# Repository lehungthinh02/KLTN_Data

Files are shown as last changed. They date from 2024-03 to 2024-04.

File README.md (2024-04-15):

# Bảng dữ liệu thiết kế

Thông tin chi tiết về các module được sử dụng trong thiết kế:

## Module (NB-IOT ME310G1)

| Thuộc tính | Giá trị |
|---|---|
| Điện áp nguồn | 3.8V |
| Dòng điện | 700 mA |
| Giao tiếp | UART, SPI, LTE  |

## MCU (PIC32MM0256GPM064)

| Thuộc tính | Giá trị |
|---|---|
| Điện áp nguồn | 2.0V đến 3.6V |
| Dòng điện | 0.65 μA đến 5 μA |
| Giao tiếp | SPI, I2C, UART, USB-OTG|

# Nguồn tài liệu

- [File 3D và danh sách bom](https://www.thingiverse.com/thing:6439737)

# Sơ đồ thiết kế

Mô tả quy trình hoạt động:

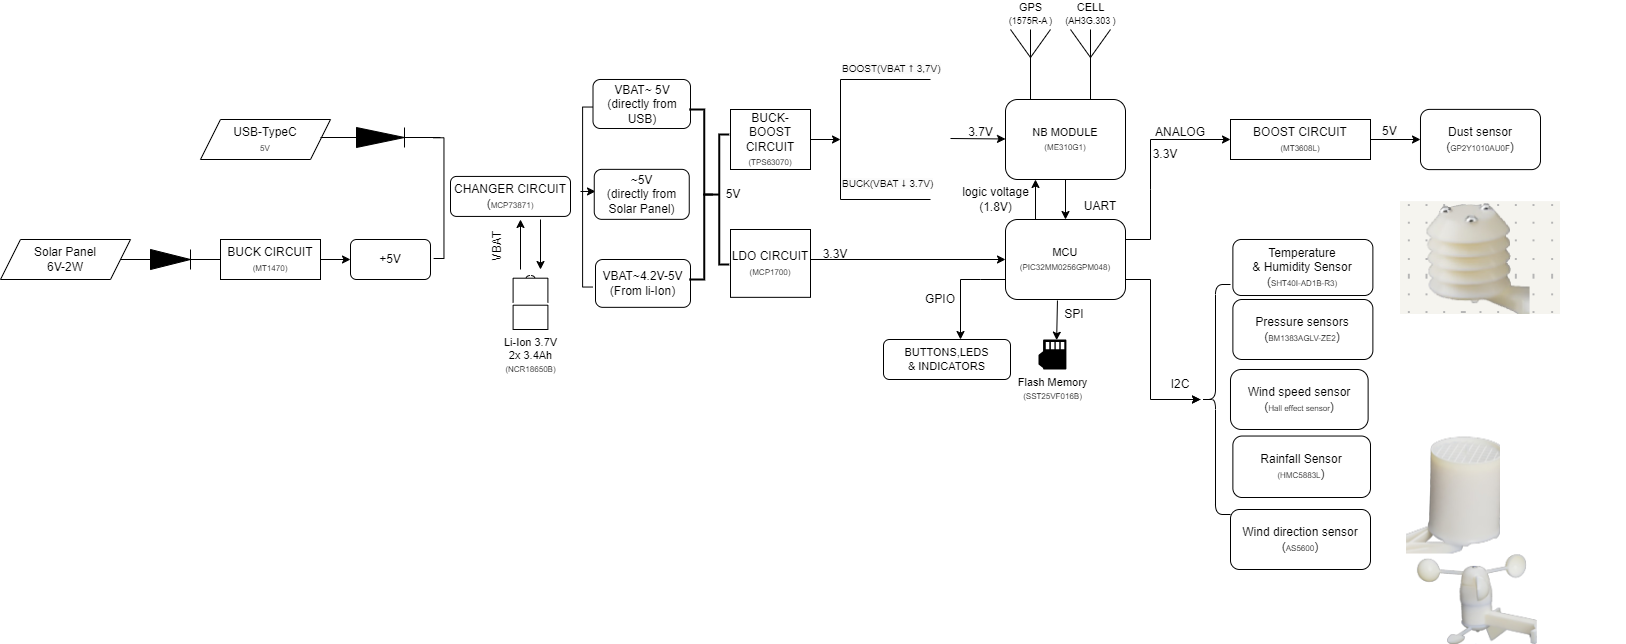
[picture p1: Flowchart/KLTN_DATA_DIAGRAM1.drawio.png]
flowchart


# Case of Board

Mô tả về case bảo vệ board:

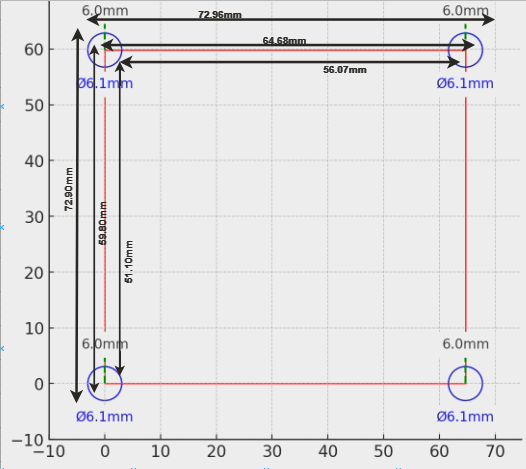
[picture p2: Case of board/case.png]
Case of Board


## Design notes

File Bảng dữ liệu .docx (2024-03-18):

Cảm biến | Điện áp nguồn | Dòng điện | Giao tiếp
Nhiệt độ-độ ẩm (HPP845E034R5) | 3.8v | 0,65 mA | I2C
Áp suất (BM1383AGLV) | 3.3v | - | I2C
Cảm biến bụi (GP2Y1010AU0F) | 5v | 11 mA | Analog
Cảm biến hướng gió (AS5600) | 3.3v | 1,5 mA | I2C
Cảm biến tốc độ gió (Hall A3144) | 4.5v-24v | - | Analog
Cảm biến từ trường đo lượng mưa(HMC5883L) | 2.16v -3.6v | 100μA | I2C

NB-IOT(ME310G1)
Điện áp nguồn | 3.8v
Dòng điện | 700 mA
Giao tiếp | UART,SPI, LTE Cat-M1/Cat-NB1,DCS/PCS, GSM

MCU(PIC32MM0256GPM064)
Điện áp nguồn | 2.0v đến 3.6v
Dòng điện | 0.65 μA đến 5 μA
Giao tiếp | SPI,I2C,UART,USB-OTG,CAN,LIN.

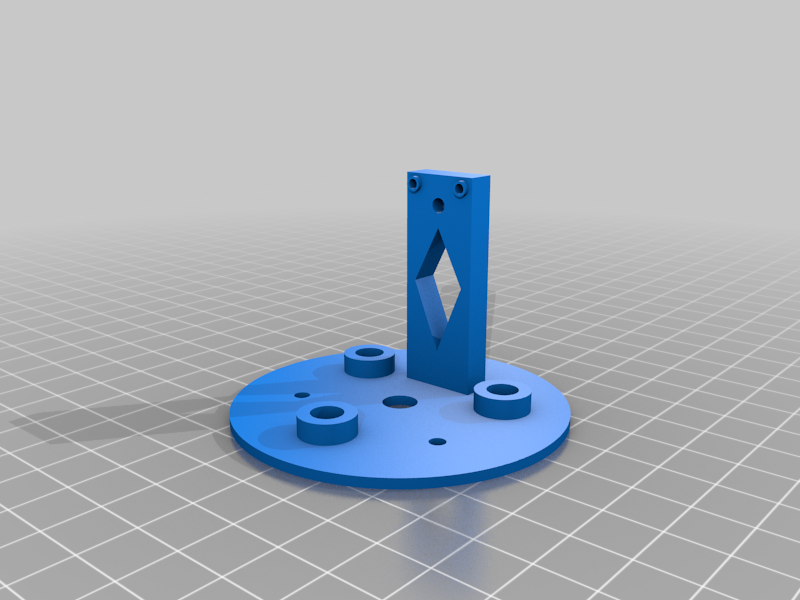
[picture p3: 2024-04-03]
Hardware/Enclosure/images/645dd349-c03a-4ee8-80c0-8387001d7b49.png

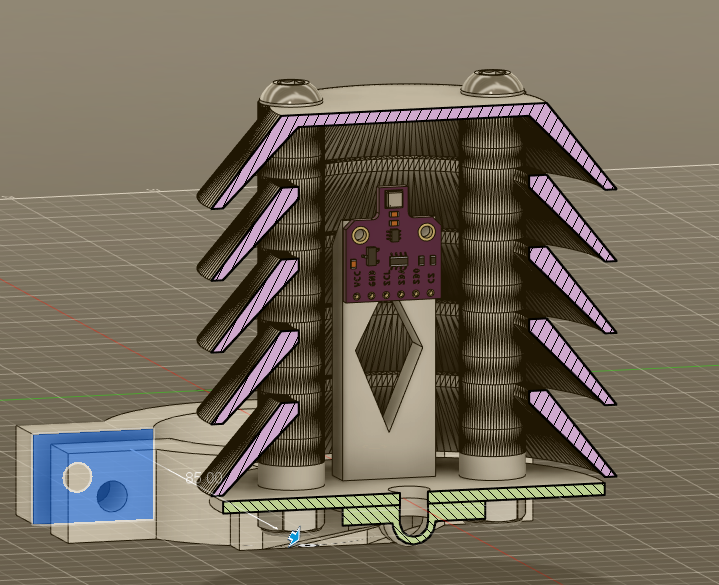
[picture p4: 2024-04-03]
Hardware/Enclosure/images/4b5391d4-0b75-4b54-ad87-2e042f95fe6b.png

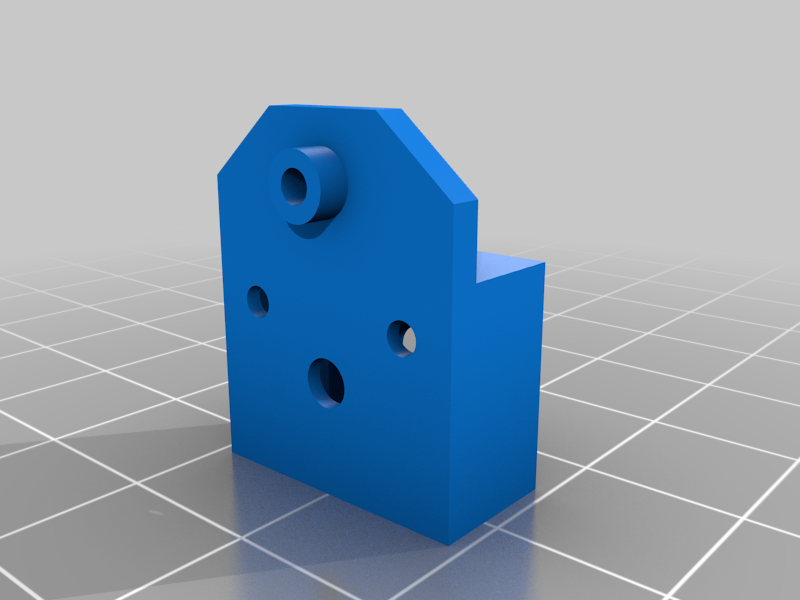
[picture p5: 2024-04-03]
Hardware/Enclosure/images/2f302a85-7f2c-48bd-ab72-bc9634dedcbf.png

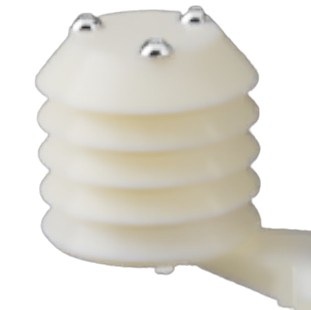
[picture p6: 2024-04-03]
Hardware/Enclosure/images/HumiditySensor.png

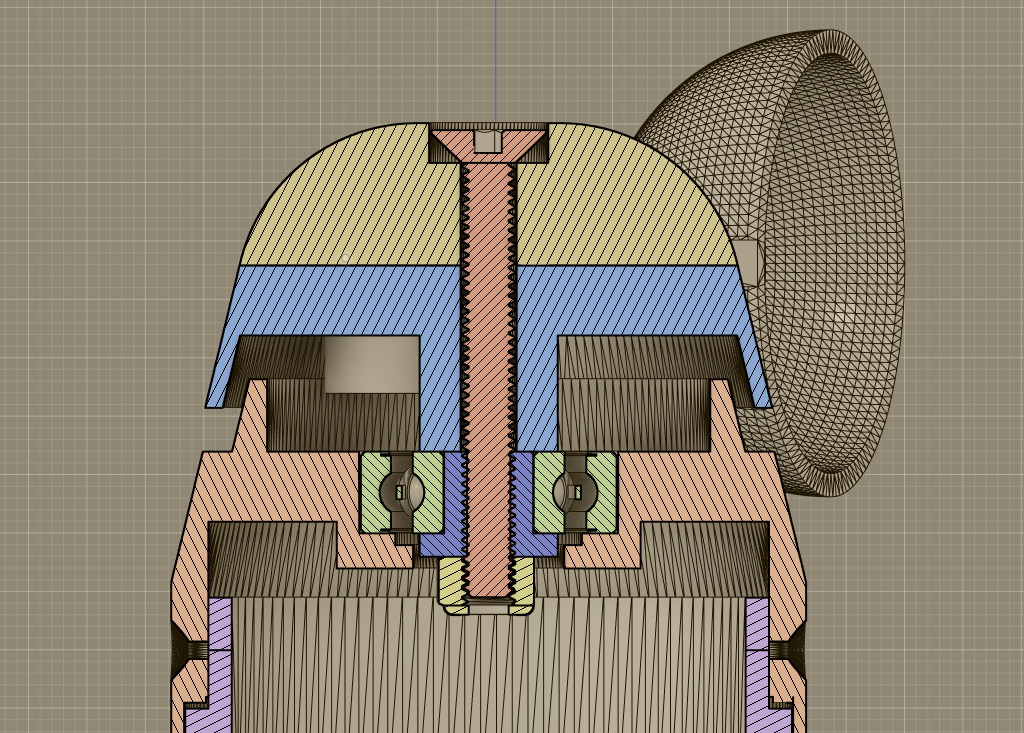
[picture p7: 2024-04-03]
Hardware/Enclosure/images/2bd4bd71-de33-4c61-b7e4-2078deda2e9a.png

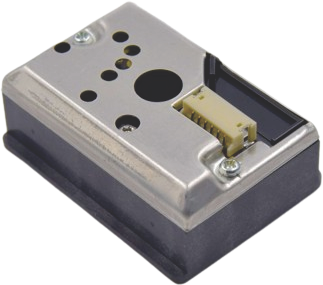
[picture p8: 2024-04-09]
Hardware/Enclosure/images/Untitled-1_Images/Untitled-1_ImgID1.png

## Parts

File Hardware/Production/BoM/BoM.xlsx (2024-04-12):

# | MNP | MFT | Description | Reference | Qty | Price | Sub-Price | Stock Link
1 | ZH1.5-10CM | OEM | ZH1.5 Bus Wire Female-Female Connector 6 Way, Pitch 1.5mm, Length 10cm | CB1 | 1 | $0.15400 | $0.15400 | https://www.thegioiic.com/day-bus-zh1-5-cai-cai-6-tiep-diem-1-5mm-dai-10cm
2 | IDC8x2-30CM | OEM | IDC Cable Female-Female Same Direction 8-Way Connector, Pitch 2.0mm, Length 30cm | CB2 | 1 | $1.00900 | $1.00900 | https://www.thegioiic.com/day-cap-idc-cai-cai-cung-huong-8-tiep-diem-2-0mm-dai-30cm
3 | IDC8x2-50CM | OEM | IDC Cable Female-Female Same Direction 8-Way Connector, Pitch 2.0mm, Length 50cm | CB3 | 1 | $1.22800 | $1.22800 | https://www.thegioiic.com/day-cap-idc-cai-cai-cung-huong-8-tiep-diem-2-0mm-dai-50cm
4 | GP2Y1014AU | SHARP | DUST SENSOR UNIT | MD3 | 1 | $4.07900 | $4.07900 | https://www.thegioiic.com/gp2y1014au-cam-bien-bui-pm2-5
~~5~~ | ~~SOLAR9V-2W-115x115x3~~ | ~~OEM~~ | ~~SOLAR CELL 2W 9V 220MA 115x115x3MM~~ | ~~J2~~ | ~~1~~ | ~~$2.85100~~ | ~~$2.85100~~ | ~~https://www.thegioiic.com/tam-nang-luong-mat-troi-2w-9v~~
6 | 1575R-A | AntennaHome | GPS ACTIVE ANT 19X19 IPEX CONNECTOR RF CABLE 10CM | MD2 | 1 | $1.05300 | $1.05300 | https://www.thegioiic.com/1575r-a-ang-ten-active-gps-19x19-dau-ipex-cap-rf-10cm
~~7~~ | ~~AH3G.303~~ | ~~AntennaHome~~ | ~~ANTENNA SMD 2G/3G/4G 690~2700MHz~~ | ~~ANT1~~ | ~~1~~ | ~~$1.09600~~ | ~~$1.09600~~ | ~~https://www.thegioiic.com/ah3g-303-ang-ten-smd-2g-3g-4g-690-2700mhz~~
8 | PRT-12895 | SparkFun | BATT LITH-ION 3.7V 2.6AH 18650 | BAT1,BAT2 | 2 | $1.40400 | $2.80800 | https://www.thegioiic.com/pin-sac-18650-1800mah-3-6v-4-2v
9 | CL10B104KA8NNNC | Samsung | CAP CER 0.1UF 25V X7R 0603 | C1,C6,C12,C16,C17,C25,C27,C34,C41,C42,C46,C47,C51,C61,C66,C70,C74 | 17 | $0.00830 | $0.14110 | https://www.thegioiic.com/tu-gom-0603-100nf-0-1uf-25v
10 | CL10C101JB8NNNC | Samsung | CAP CER 100PF 50V C0G/NP0 0603 | C4,C9,C10,C11,C13,C15,C23,C68,C69 | 9 | $0.00830 | $0.07470 | https://www.thegioiic.com/tu-gom-0603-100pf-50v
11 | CL10B225KP8NNNC | Samsung | CAP CER 2.2UF 10V X7R 0603 | C8,C31,C36,C44,C50,C55,C60 | 7 | $0.01800 | $0.12600 | https://www.thegioiic.com/tu-gom-0603-2-2uf-10v
12 | CL10C8R2DB8NNNC | Samsung | CAP CER 8.2PF 50V C0G/NP0 0603 | C28,C29 | 2 | $0.00830 | $0.01660 | https://www.thegioiic.com/tu-gom-0603-8-2pf-50v
13 | CL10C220JB8NFNC | Samsung | CAP CER 22PF 50V C0G/NP0 0603 | C32,C33,C35,C37,C38,C39,C40,C43,C45,C48,C52,C53,C54,C56,C59,C71,C73 | 17 | $0.00830 | $0.14110 | https://www.thegioiic.com/tu-gom-0603-22pf-50v
14 | CL21A106KOQNNNE | Samsung | CAP CER 10UF 16V X5R 0805 | C2,C3,C7,C14,C18,C21,C22,C24,C30,C62,C63,C64,C67,C75 | 14 | $0.01700 | $0.23800 | https://www.thegioiic.com/tu-gom-0805-10uf-16v
15 | TAJC227K006RNJ | AVX | CAP ALUM 220UF 20% 6.3V SMD 2312 | C19,C20,C26,C49,C65,C72 | 6 | $0.24100 | $1.44600 | https://www.thegioiic.com/tu-tantalum-220uf-6-3v-2312-tajc227k006rnj
16 | UUD1E471MNL1GS | Nichicon | CAP ALUM 470UF 20% 25V SMD | C5 | 1 | $0.08800 | $0.08800 | https://www.thegioiic.com/tu-nhom-smd-470uf-25v-10x10-5mm
17 | PH2RA-04-UA | Adam Tech | CONN HEADER R/A 2x2POS 2.54MM | J3 | 1 | $0.11000 | $0.11000 | https://www.thegioiic.com/hang-rao-duc-doi-2-54mm-80-chan-cong-2-hang-xuyen-lo
18 | PR20B05VBDN | METZ | PIN HEADER, THR, DUAL ROW, 1.27 | J4 | 1 | $0.19700 | $0.19700 | https://www.thegioiic.com/hang-rao-duc-doi-1-27mm-80-chan-2-hang-cao-7-2mm-xuyen-lo
19 | SS26 | MDD | DIODE SCHOTTKY 60V 2A SMA | D1,D2,D8 | 3 | $0.01800 | $0.05400 | https://www.thegioiic.com/ss26-sma-diode-schottky-2a
20 | DPS368XTSA1 | Infineon | SENSOR 17.4PSIG 24BIT 8VLGA | U14 | 1 | $3.18000 | $3.18000 | https://www.digikey.com/en/products/detail/infineon-technologies/DPS368XTSA1/10244079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
21 | MF-MSMF075/24-2 | Bourns | PTC RESET FUSE 24V 750MA 1812 | F1 | 1 | $0.15400 | $0.15400 | https://www.thegioiic.com/mf-msmf075-24-2-cau-chi-tu-phuc-hoi-1812-24v-0-75a
22 | XH2.54-4P-R | OEM | PIN HEADER R/A 1x4POS 2.54MM | J1 | 1 | $0.01300 | $0.01300 | https://www.thegioiic.com/dau-xh-2-54mm-4-chan-cong-xuyen-lo
23 | DF11-8DP-2DSA(08) | Hirose | CONN HEADER VERT 8POS 2MM | J6,J7,J8 | 3 | $0.07900 | $0.23700 | https://www.thegioiic.com/cong-dc3-8-chan-2-hang-2-0mm-chan-thang
24 | S6B-ZR-SM4A-TF | JST | CONN HEADER SMD R/A 6POS 1.5MM | U11 | 1 | $0.03500 | $0.03500 | https://www.thegioiic.com/dau-zh-1-5mm-6-chan-dan-smd-nam-ngang
25 | HBLS1608-47NJ | HYHONGYEX | FIXED IND 47NH 380MA 700MOHM SMD 0603 | L3 | 1 | $0.01800 | $0.01800 | https://www.thegioiic.com/hbls1608-47nj-cuon-cam-47nh-0603-380ma
26 | BK2125HS101-T | Taiyo Yuden | FERRITE BEAD 100 OHM 0805 1LN | FT1 | 1 | $0.01800 | $0.01800 | https://www.thegioiic.com/bk2125hs101-t-ferrite-beads-100-ohm-0805
27 | SDE0604A-2R2M | Bourns | FIXED IND 2.2UH 4.35A 31MOHM SMD 5852 | L1 | 1 | $0.04400 | $0.04400 | https://www.thegioiic.com/cuon-cam-dan-smd-cd53-5852-2r2-2-2uh-3-5a
28 | SDE0805A-100M | Bourns | FIXED IND 10UH 3.2A 70 MOHM SMD | L2,L4 | 2 | $0.04400 | $0.08800 | https://www.thegioiic.com/cuon-cam-dan-smd-cd75-7855-100-10uh-2-3a
29 | B1931USD-20D000814U1930 | Harvatek | LED RED DIFFUSED 0603 SMD | D3 | 1 | $0.01500 | $0.01500 | https://www.thegioiic.com/led-do-0603-dan-smd-trong-suot-harvatek
30 | B1931NG--20D001114U1930 | Harvatek | LED GREEN DIFFUSED 0603 SMD | D4 | 1 | $0.01500 | $0.01500 | https://www.thegioiic.com/led-xanh-la-0603-dan-smd-trong-suot-harvatek
31 | B1911UD--20D001014U1930 | Harvatek | LED ORANGE DIFFUSED 0603 SMD | D5 | 1 | $0.01500 | $0.01500 | https://www.thegioiic.com/led-cam-0603-dan-smd-trong-suot-harvatek
32 | E1221NB--05D000814U1930 | Harvatek | LED BLUE DIFFUSED 0603 SMD | D7 | 1 | $0.01500 | $0.01500 | https://www.thegioiic.com/led-xanh-duong-0603-dan-smd-trong-suot-harvatek
33 | TPS630701RNMR | TI | IC REG BCK BST 5V 2A 15VQFN | U2 | 1 | $1.89000 | $1.89000 | https://www.digikey.com/en/products/detail/texas-instruments/TPS630701RNMR/6175215
34 | AC0603JR-071KL | YAGEO | RES SMD 1K OHM 5% 1/10W 0603 | R1,R6,R10,R13,R14,R15,R26,R28,R31,R32,R36 | 11 | $0.00140 | $0.01540 | https://www.thegioiic.com/dien-tro-1-kohm-0603-5-
35 | RC0603FR-075K1L | YAGEO | RES SMD 5.1K OHM 1% 1/10W 0603 | R2,R5,R23,R24 | 4 | $0.00200 | $0.00800 | https://www.digikey.com/en/products/detail/yageo/RC0603FR-075K1L/727268
36 | RC0603FR-0710KL | YAGEO | RES SMD 10K OHM 1% 1/10W 0603 | R3,R4,R9,R12,R16,R18,R20,R22,R25,R30,R35 | 11 | $0.00200 | $0.02200 | https://www.thegioiic.com/dien-tro-10-kohm-0603-1-
37 | AC0603FR-0775KL | YAGEO | RES SMD 75K OHM 1% 1/10W 0603 | R7,R34 | 2 | $0.00200 | $0.00400 | https://www.thegioiic.com/dien-tro-75-kohm-0603-1-
38 | RT0603FRE0736KL | YAGEO | RES SMD 36K OHM 1% 1/10W 0603 | R8 | 1 | $0.00200 | $0.00200 | https://www.digikey.com/en/products/detail/yageo/RT0603FRE0736KL/1075328
39 | RC0603FR-0753K6L | YAGEO | RES SMD 53.6K OHM 1% 1/10W 0603 | R11 | 1 | $0.00200 | $0.00200 | https://www.thegioiic.com/dien-tro-53-6-kohm-0603-1-
40 | RC0603FR-07100KL | YAGEO | RES SMD 100K OHM 1% 1/10W 0603 | R17 | 1 | $0.00200 | $0.00200 | https://www.thegioiic.com/dien-tro-100-kohm-0603-1-
41 | RC0603FR-07680KL | YAGEO | RES SMD 680K OHM 1% 1/10W 0603 | R19 | 1 | $0.00200 | $0.00200 | https://www.thegioiic.com/dien-tro-680-kohm-0603-1-
42 | RC0603JR-070RL | YAGEO | RES SMD 0 OHM JUMPER 1/10W 0603 | R21,R27,R29,Z1 | 4 | $0.00200 | $0.00800 | https://www.thegioiic.com/dien-tro-0-ohm-0603-1-
43 | RC0603JR-07150RL | YAGEO | RES SMD 150 OHM 5% 1/10W 0603 | R33 | 1 | $0.00140 | $0.00140 | https://www.thegioiic.com/dien-tro-150-ohm-0603-5-
44 | RC0603FR-13150KL | YAGEO | RES SMD 150K OHM 1% 1/10W 0603 | R37,R38 | 2 | $0.00200 | $0.00400 | https://www.thegioiic.com/dien-tro-150-kohm-0603-1-
45 | VEC2R7106QC | VinaTech | SUPERCAP EDLC 10F 2.7V ESR 55mR | C57,C58 | 2 | $1.12850 | $2.25700 | https://banlinhkien.com/sieu-tu-10f-2.7v-10x30mm-vec2r7106qc-p12117721.html
46 | SHT40I-AD1B-R3 | Sensirion | INDUSTRIAL SENSOR HUMID/TEMP | U12 | 1 | $2.10000 | $2.10000 | https://www.digikey.com/en/products/detail/sensirion-ag/SHT40I-AD1B-R3/15792545
47 | SIM8051-6-0-14-01-A | GCT | NANO SIM PUSH PULL, 6P, SMT, 1.3 | J5 | 1 | $0.15400 | $0.15400 | https://www.thegioiic.com/ns-ol-6p-khay-cam-nanosim-6-chan-open-lock
48 | MC-146 32.7680KA-AC0: ROHS | EPSON | CRYSTAL 32.7680KHZ 9PF SMD | X1 | 1 | $0.15400 | $0.15400 | https://www.thegioiic.com/thach-anh-32-768khz-mc-146-crystal-7015-4-chan
~~49~~ | ~~SST25VF016B-50-4C-S2AF~~ | ~~Microchip~~ | ~~IC FLASH 16MBIT SPI 50MHZ 8SOIC~~ | ~~U6~~ | ~~1~~ | ~~$0.00000~~ | ~~$0.00000~~ | ~~https://www.digikey.com/en/products/detail/microchip-technology/SST25VF016B-50-4C-S2AF/2297794~~
50 | SI2300DS-T1-GE3 | Vishay | MOSFET N-CH 30V 3.6A SOT23-3 | Q1,Q2 | 2 | $0.02200 | $0.04400 | https://www.thegioiic.com/si2300ds-mosfet-kenh-n-30v-3-6a-sot-23
51 | MCP1700T-3302E/TT | Microchip | IC REG LINEAR 3.3V 250MA SOT23-3 | U5 | 1 | $0.13200 | $0.13200 | https://www.thegioiic.com/mcp1700t-3302e-tt-ic-on-ap-3-3v-250ma
52 | SMF05CT1G | Onsemi | TVS DIODE 5VWM 12.5V SC88/SC70-6 | D6 | 1 | $0.03100 | $0.03100 | https://www.thegioiic.com/smf05c-esd-protection-diode-array-sot-363
53 | LM66100DCKR | TI | IC OR CTRLR IDEAL DIODE SC70-6 | U3 | 1 | $0.41000 | $0.41000 | https://www.digikey.com/en/products/detail/texas-instruments/LM66100DCKR/10273183
54 | RT9193-33GB | Richtek | IC REG LINEAR 3.3V 300MA SOT23-5 | U10 | 1 | $0.13200 | $0.13200 | https://www.thegioiic.com/rt9193-33gb-ic-on-ap-3-3v-300ma
55 | MT1470 | AEROSEMI | IC BUCK REG MULTI CONFIG ADJ SOT-23-6 | U1 | 1 | $0.08300 | $0.08300 | https://www.thegioiic.com/mt1470-ic-dieu-chinh-giam-ap-2a-sot-23-6
56 | SN74LVC1T45DBVR | TI | IC TRANSLATOR BIDIR SOT23-6 | U8,U9 | 2 | $0.21900 | $0.43800 | https://www.thegioiic.com/sn74lvc1t45dbvr-ic-voltage-level-shifter-bus-transceiver-6-sot-23
57 | MT3608L | AEROSEMI | IC BOOST REG MULTI CONFIG ADJ SOT-23-6 | U13 | 1 | $0.13200 | $0.13200 | https://www.thegioiic.com/mt3608-ic-dieu-chinh-tang-ap-2a-sot-23-6
58 | EVQ-PE105K | Panasonic | SWITCH TACTILE SPST-NO 0.05A 12V | BT1 | 1 | $0.02200 | $0.02200 | https://www.thegioiic.com/nut-nhan-3x6mm-cao-5mm-2-chan-smd-dau-trang
59 | EVQ-PE105K | Panasonic | SWITCH TACTILE SPST-NO 0.05A 12V | BT2 | 1 | $0.02200 | $0.02200 | https://www.thegioiic.com/nut-nhan-3x6mm-cao-5mm-2-chan-smd-dau-trang
~~60~~ | ~~PIC32MM0256GPM048-I/PT~~ | ~~Microchip~~ | ~~IC MCU 32BIT 256KB FLASH 48TQFP~~ | ~~U7~~ | ~~1~~ | ~~$0.00000~~ | ~~$0.00000~~ | ~~https://www.digikey.com/en/products/detail/microchip-technology/PIC32MM0256GPM048-I-PT/7354721~~
61 | U.FL-R-SMT-1(40) | Hirose | CONN U.FL RCPT STR 50 OHM SMD | ANT2 | 1 | $0.07000 | $0.07000 | https://www.thegioiic.com/cong-rf-1th-ipex-u-fl-r-smt-2-chan-dan-smd
62 | MCP73871T-2CCI/ML | Microchip | IC BATT CHG LI-ION 1CELL 4.2V 20QFN | U4 | 1 | $2.41000 | $2.41000 | https://www.digikey.com/en/products/detail/microchip-technology/MCP73871T-2CCI-ML/1680976
~~63~~ | ~~ME310G1WW05T060400~~ | ~~Telit~~ | ~~RF TXRX MODULE AT&T/VZW~~ | ~~MD1~~ | ~~1~~ | ~~$0.00000~~ | ~~$0.00000~~ | ~~https://www.digikey.com/en/products/detail/telit-cinterion/ME310G1WW05T060400/20484831~~
 |  |  |  |  |  |  | $31.30930

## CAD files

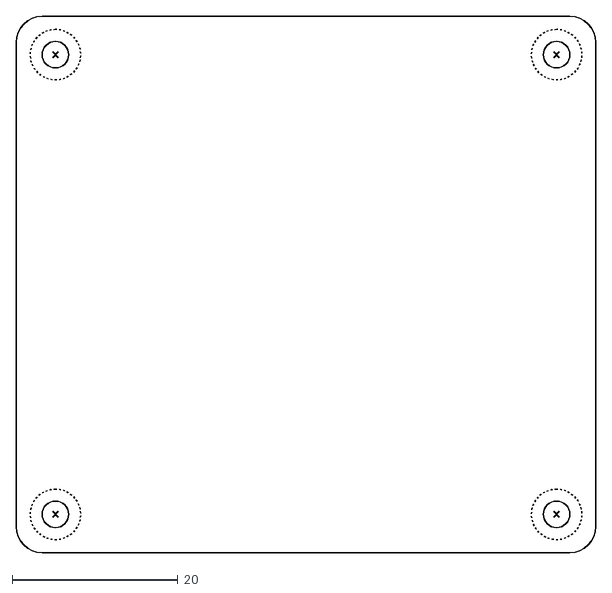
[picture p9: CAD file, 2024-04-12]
Hardware/Docs/PCBOutline.dxf
70.0 x 64.7

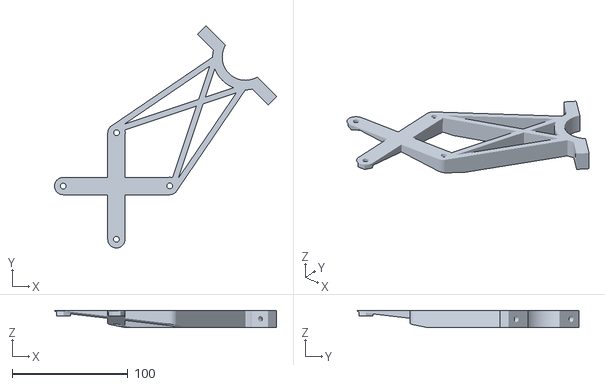
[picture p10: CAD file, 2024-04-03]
Hardware/Enclosure/files/Pluvio-Base_holder_V2.stl
191.8 x 191.8 x 15.0

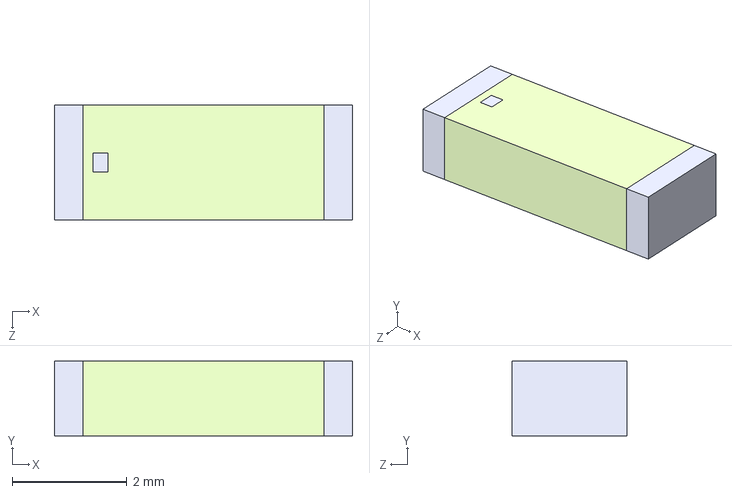
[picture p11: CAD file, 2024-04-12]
Hardware/Model3D/XCVR_YC0010AA.step
5.20 x 1.30 x 2.00 mm

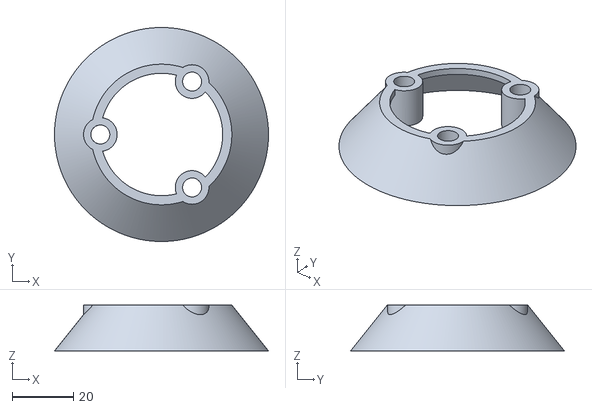
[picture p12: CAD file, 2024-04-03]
Hardware/Enclosure/files/sensor_Hub_Shield_1.stl
70.0 x 70.0 x 15.0

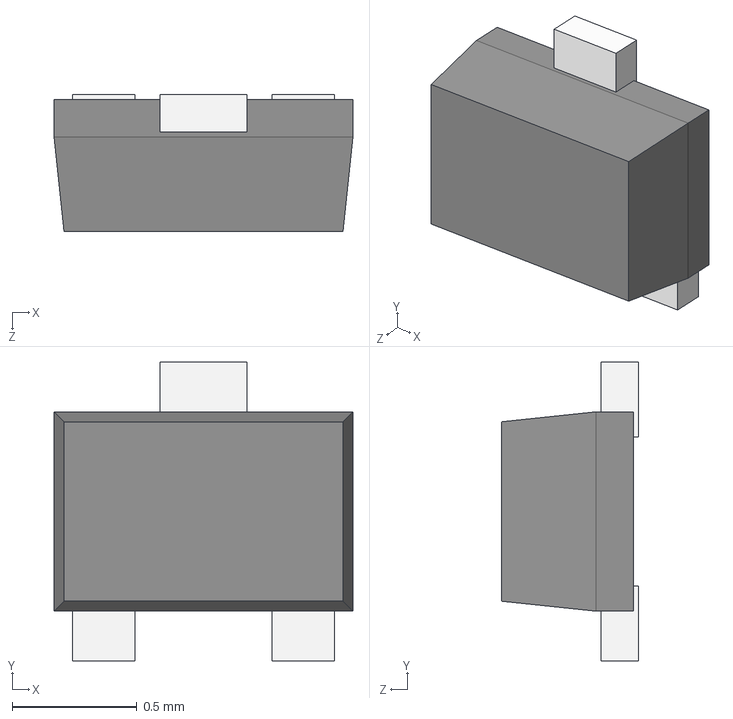
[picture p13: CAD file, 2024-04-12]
Hardware/Model3D/SOT-723_SC-105AA_VMT3_1.2x0.8x0.55.step
1.20 x 1.20 x 0.55 mm

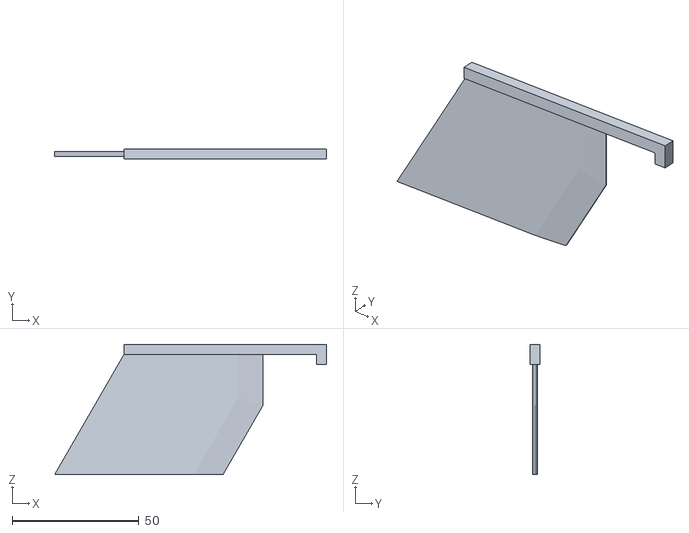
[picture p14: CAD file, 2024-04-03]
Hardware/Enclosure/files/Anemo_bottom-Wing.stl
107.4 x 4.00 x 51.5

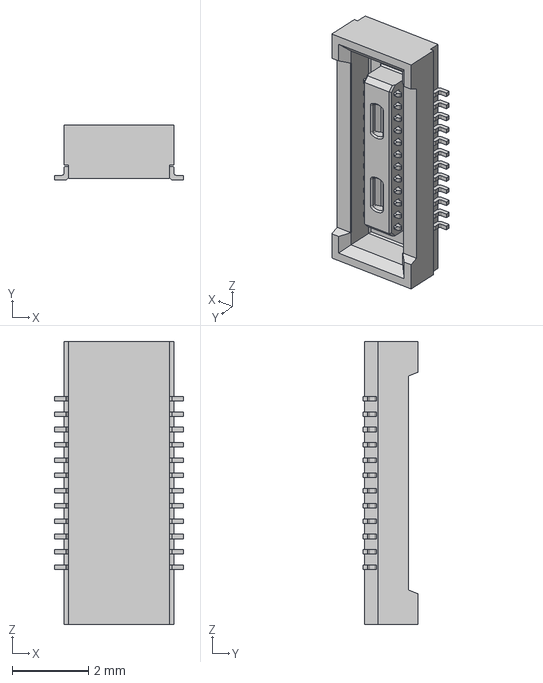
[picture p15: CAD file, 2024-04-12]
Hardware/Model3D/DF40C-24DS.stp
3.38 x 1.45 x 7.40 mm

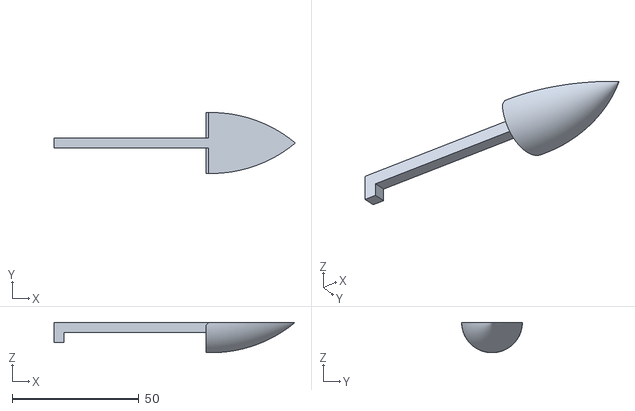
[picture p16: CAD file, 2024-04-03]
Hardware/Enclosure/files/Anemo_bottom-Tip.stl
95.0 x 24.0 x 12.0

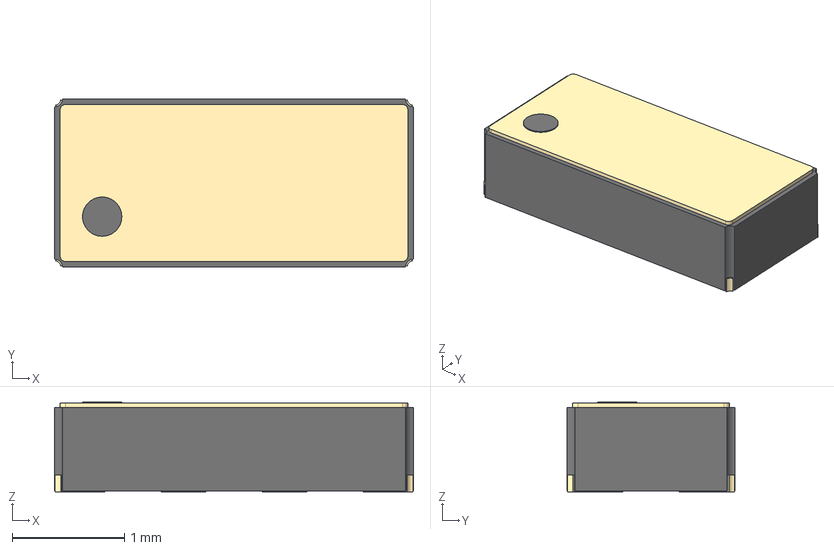
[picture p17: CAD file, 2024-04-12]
Hardware/Model3D/RV8263C7.step
3.20 x 1.50 x 0.8 mm
Rect2
Rect3
Rect4
Rect5
Terminal

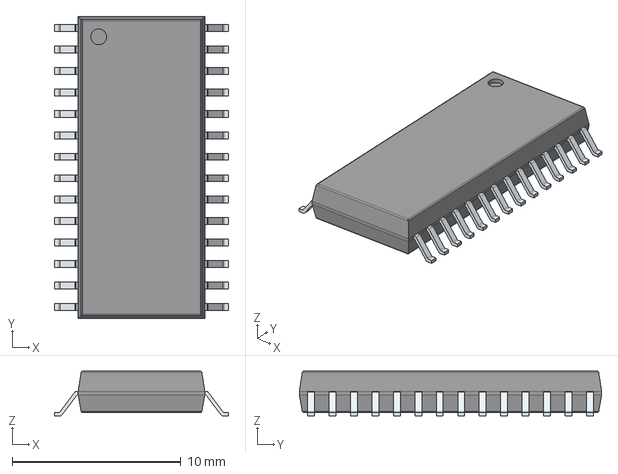
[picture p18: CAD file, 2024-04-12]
Hardware/Model3D/SOIC127P1030X265-28N.step
10.3 x 17.9 x 2.65 mm
PinsArrayLR

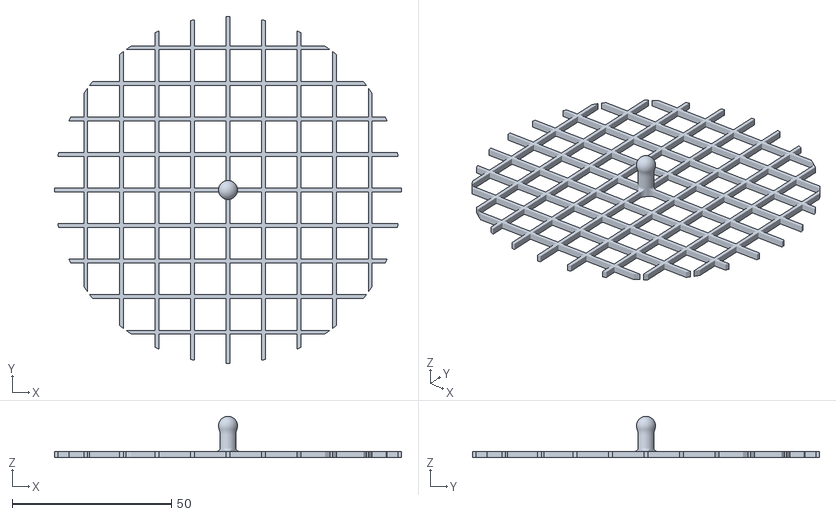
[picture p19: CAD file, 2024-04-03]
Hardware/Enclosure/files/Pluvio_Top_Mesh.stl
109.0 x 109.0 x 13.0

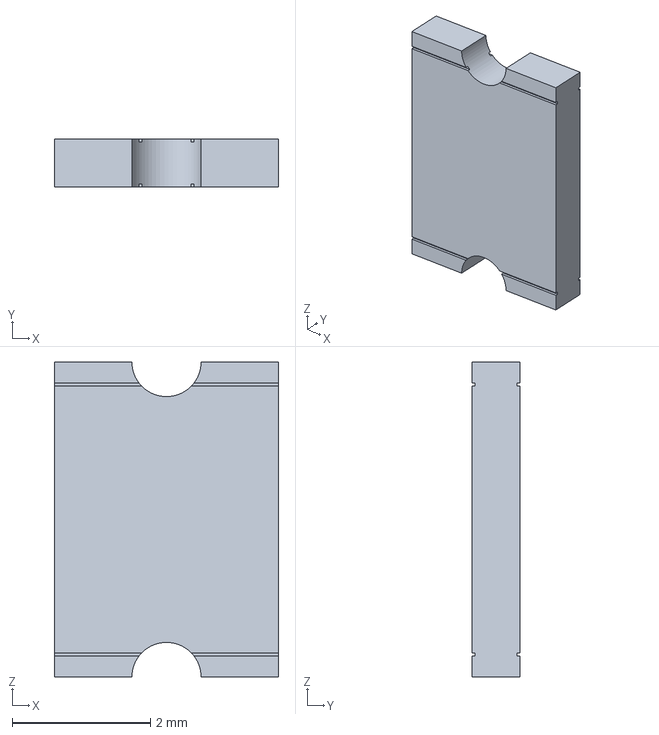
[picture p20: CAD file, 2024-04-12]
Hardware/Model3D/mf-msmf050.stp
3.24 x 0.7 x 4.55 mm

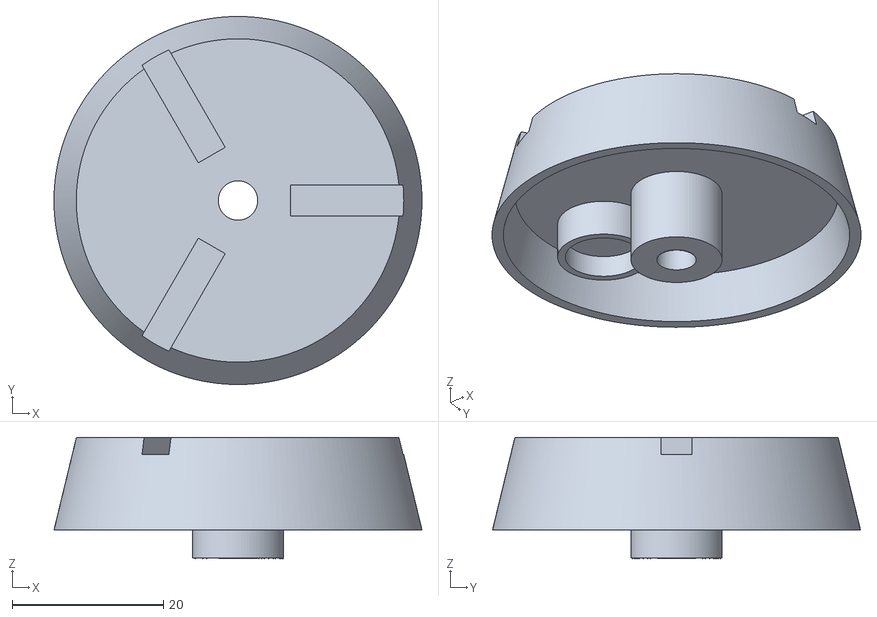
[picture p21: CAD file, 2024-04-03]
Hardware/Enclosure/files/Anemo_top_-_Interrupter.stl
48.6 x 48.6 x 16.0

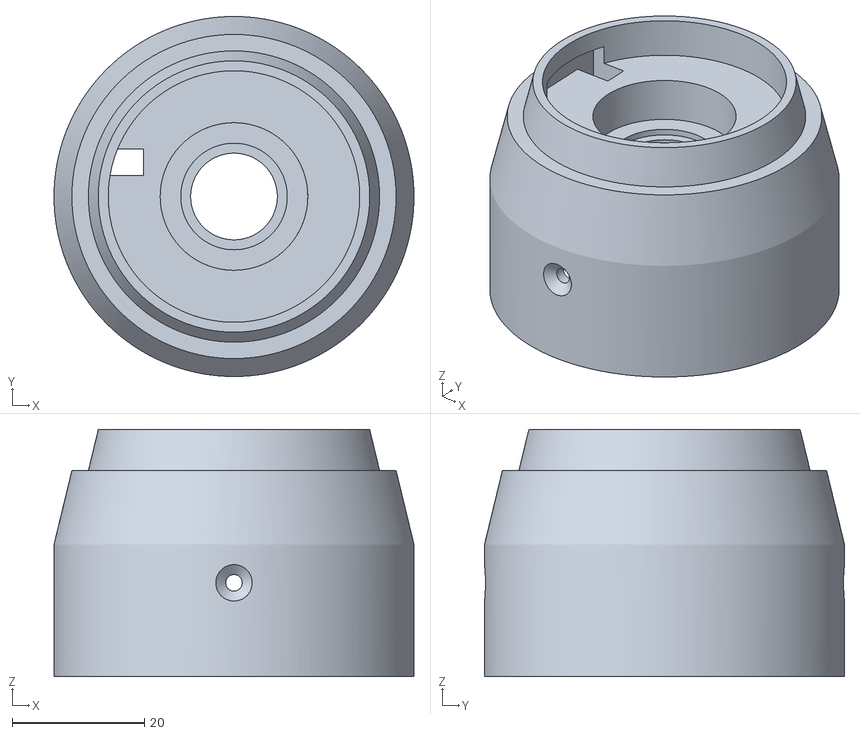
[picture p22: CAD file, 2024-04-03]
Hardware/Enclosure/files/Anemo_top_-_Base_FIXED.stl
54.4 x 54.4 x 37.4

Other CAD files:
Hardware/Enclosure/files/Sensor_Hub_Shield_2.stl
Hardware/Enclosure/files/Anemo_top_-_Cap.stl
Hardware/Model3D/0612R.step
Hardware/Enclosure/files/Anemo_top_-_Wind_bowl.stl
Hardware/Enclosure/files/Anemo-Endscrew_Top_FIXED.stl
Hardware/Enclosure/files/Anemo_-_EndScrew_Bottom_FIXED.stl
Hardware/Enclosure/files/Anemo_Backpole.stl
Hardware/Enclosure/files/Anemo_bottom-Base.stl
Hardware/Enclosure/files/Anemo_bottom-High_cap_FIXED.stl
Hardware/Enclosure/files/Anemo_bottom-Low_cap_FIXED.stl
Hardware/Enclosure/files/Pluvio-Backpole_V2.stl
Hardware/Enclosure/files/Pluvio_-_Base_FIXED.stl
Hardware/Enclosure/files/Pluvio_-_Tipping_bucket_FIXED.stl
Hardware/Enclosure/files/Pluvio_Case.stl
Hardware/Enclosure/files/Pluvio_sensor_Hub.stl
Hardware/Enclosure/files/SH-DHT_holder.stl
Hardware/Enclosure/files/SH-First.stl
Hardware/Enclosure/files/Sensor_Hub_Backpole.stl
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

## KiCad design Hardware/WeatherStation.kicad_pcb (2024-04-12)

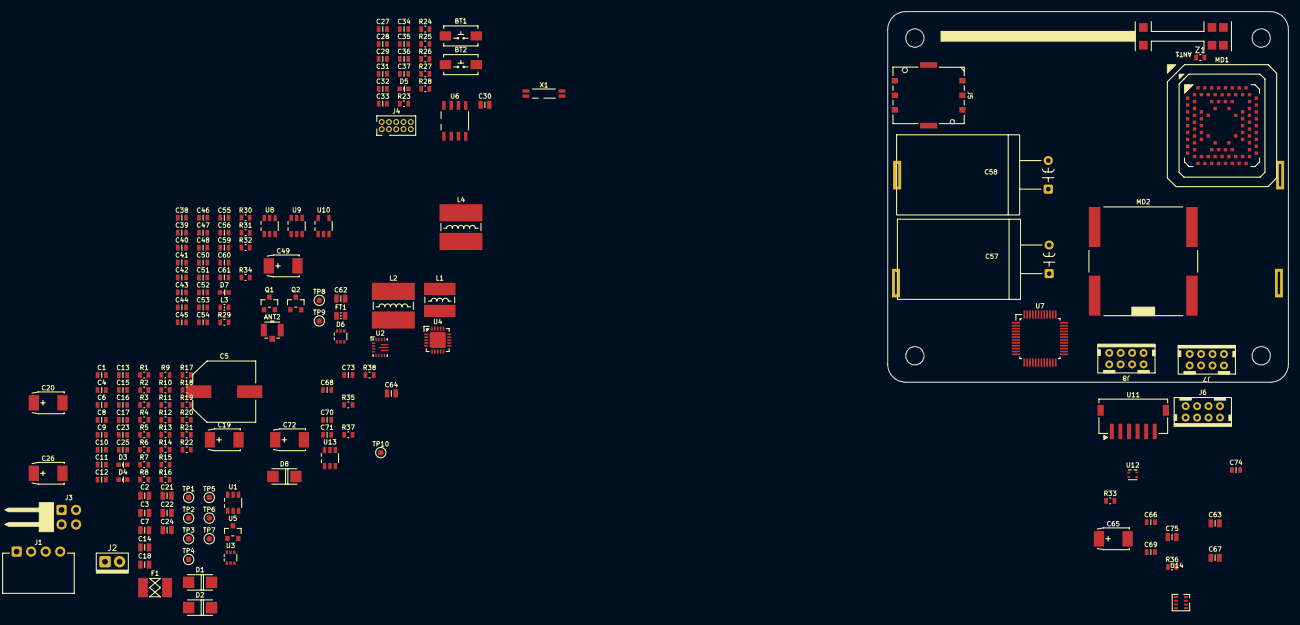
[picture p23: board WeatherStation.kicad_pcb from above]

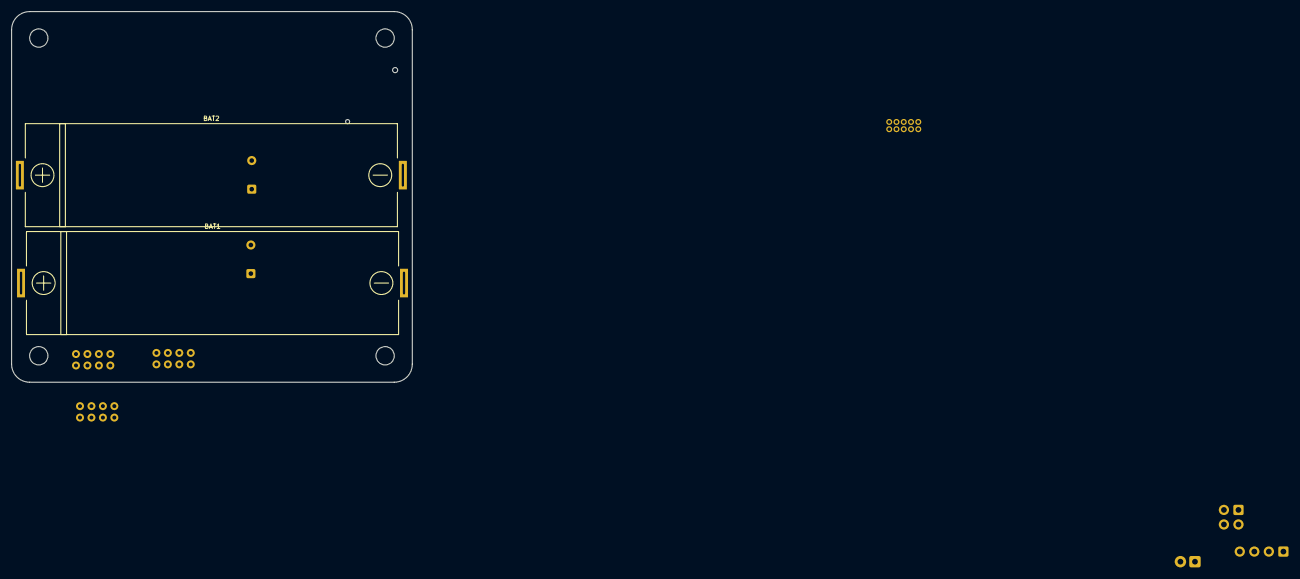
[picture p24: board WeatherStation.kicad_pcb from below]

Board: 2 copper layers, 70.0 x 64.7 mm, 171 parts (2 on the bottom side), 92 nets, no tracks yet.

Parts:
ANT1: 0.9-1.8GHz; AH3G.303
ANT2: UFL; U.FL
BAT1, BAT2: 3.7V/1.8Ah; BAT18650-PCBPAD
BT1: RESET; SW_SMD2_6.0x3.5
BT2: APP; SW_SMD2_6.0x3.5
C1, C6, C12, C16, C17, C25, C27, C34, C41, C42, C46, C47, C51, C61, C66, C70, C74: 100nF; CAP0603
C2, C3, C7, C14, C18, C21, C22, C24, C30, C62, C63, C64, C67, C75: 10uF; CAP0805
C4, C9, C10, C11, C13, C15, C23, C68, C69: 100pF; CAP0603
C5: 470uF; CAP_ELEC-10.3x10.3-DIA10
C8, C31, C36, C44, C50, C55, C60: 2.2uF; CAP0603
C19, C20, C26, C49, C65, C72: 220uF; CAP2312-6032
C28, C29: 8.2pF; CAP0603
C32, C33, C35, C37, C38, C39, C40, C43, C45, C48, C52, C53, C54, C56, C59, C71, C73: 22pF; CAP0603
C57, C58: 10F/2.7V; SCAP1320
D1, D2, D8: 2A/0.5VF; DO-214AC
D3: LOW BAT; LED0603
D4: CHARGE; LED0603
D5: APP; LED0603
D6: TVS-5CH; SOT363
D7: NB; LED0603
F1: 750mA/6.3V; FUSE1812
FT1: 100R@100MHz; IND0805
J1: USB; HDM-1x4x2.54-TH-RA
J2: SOLAR; PAD02_2.54TH
J3: PWR MONITOR; DIL04_2.54_MTHRA
J4: RPDBG; DIL10_1.27_MTH
J5: NANOSIM; SIM8051-6-0-14-01-A_GCT
J6, J7, J8: DIL08; HDM-2x4x2.0-TH-RA
L1: 2.2uH/3A; IND5852
L2, L4: 10uH/3A; IND7870
L3: 47nH; IND0603
MD1: NB-IoT MODULE; xE310
MD2: GPS ACTIVE ANTENNA; 1575R-A
Q1, Q2: MFET N; SOT23
R1, R6, R10, R13, R14, R15, R26, R28, R31, R32, R36: 1K; RES0603
R2, R5, R23, R24: 5.1K, 1%; RES0603
R3, R4, R9, R12, R16, R18, R20, R22, R25, R30, R35: 10K, 1%; RES0603
R7, R34: 75K, 1%; RES0603
R8: 36K, 1%; RES0603
R11: 53.6K, 1%; RES0603
R17: 100K, 1%; RES0603
R19: 680K, 1%; RES0603
R21, R27, R29: 0R; RES0603
R33: 150R; RES0603
R37, R38: 150K, 1%; RES0603
TP1: VUSB; TP1MM
TP2: VNB; TP1MM
TP3: 5V; TP1MM
TP4: 3V3; TP1MM
TP5: VBAT; TP1MM
TP6: GND; TP1MM
TP7: VDD; TP1MM
TP8: 1V8; TP1MM
TP9: VLNA; TP1MM
TP10: VBOOST; TP1MM
U1: BUCK 5V; SOT-23-6_MCHP
U2: BUCK-BOOST 3.8V; PowerVQFN15_TI
U3: IDEAL DIODE; SOT363
U4: MCP73871; VQFN20-4x4_MCHP
U5: MCP1700; SOT23
U6: SPI Memory; SOIC8_3.9_MCHP
U7: PIC32MM MCU; TQFP48-7x7_MCHP
U8, U9: LEVEL SHIFT 1-CH; SOT-23-6_MCHP
U10: LDO 3.3V/300mA; SOT-23-5_MCHP
U11: DUST SENSOR CONNECTOR; HDM-6x1.5-SMD-RA
U12: HUMI & TEMP; SHT4x
U13: BOOST 5V; SOT-23-6_MCHP
U14: DPS368
X1: 32.768kHz; SMD4-7015
Z1: 0R; RES0603

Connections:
+1V8: C46.1, C47.1, C51.1, MD1.N16 (~ONOFF/~WAKE), TP8.1, U8.6 (VCCB), U9.1 (VCCA), U9.5 (DIR)
+3.3V: C24.1, C27.1, C31.2, C33.1, C34.1, C36.1, C37.1, D3.A, J4.4 (VDD), J7.1, J8.1, R22.1, R23.2, R24.2, R25.1, R37.1, R38.1, TP4.1, U5.2 (VOUT), U6.3 (~WP), U6.7 (~HOLD), U6.8 (VDD), U7.11 (VUSB3V3), U7.18 (AVDD/VDD), U7.30 (VDD), U7.43 (VDD)
+5V: C11.1, C12.1, C14.1, C17.1, C20.+, D2.K, D4.A, R11.1, TP3.1, U3.6 (VOUT), U4.2 (VPCC), U4.4 (PROG2), U4.17 (CE), U4.18 (IN), U4.19 (IN)
/MCU/DBG_RXD: J4.3 (DBG_RX), U7.26 (TDI/AN11/C1INA/RP9/SCL2/OCM2F/RB3)
/MCU/DBG_TXD: J4.1 (DBG_TXD), U7.25 (AN4/C1INB/RP8/SDA2/OCM2E/RB2)
/MCU/NB_DN: J4.7 (USB_DM), MD1.V18 (USB_D-)
/MCU/NB_DP: J4.5 (USB_DP), MD1.U19 (USB_D+)
/MCU/NB_VBUS: J4.9 (USB_VBUS), R29.1
/MCU/PGC: J4.10 (PGC), U7.24 (PGEC1/AN3/C1INC/C2INA/RP7/OCM2D/RB1)
/MCU/PGD: J4.8 (PGD/UPDI), U7.23 (PGED1/AN2/C1IND/C2INB/C3INC/RP6/RB0)
/MCU/SCL: J7.7, J8.2, R24.1
/MCU/SDA: J7.8, J8.3, R23.1
/MCU/SOSCI: C28.1, U7.35 (SOSCI/AN7/RP10/OCM3C/RB4), X1.1 (X1)
/MCU/SOSCO: C29.1, U7.36 (SOSCO/SCLKI/RP5/PWRLCLK/OCM3D/RA4), X1.4 (X2)
/MCU/USB_DN: J1.3, U7.9 (D-/RB10)
/MCU/USB_DP: J1.2, U7.10 (D+/RB11)
/MCU/V5V_SEN: C15.1, R13.1
/MCU/VBAT_SEN: C23.1, R19.2, R20.1
/MCU/VBUS_SEN: C9.1, R6.1, U7.46 (VBUS/RB6)
/MCU/VNB_EN: R27.1, U2.1 (PS/SYNC), U2.14 (EN)
/MCU/VNB_SEN: C13.1, R10.1
/MCU/VSOLAR_SEN: C4.1, R1.1
/MCU/~BT_APP: BT2.1, C35.1, R25.2
/MCU/~MCLR: BT1.1, C32.1, J4.2 (~RESET), R22.2, U7.19 (~MCLR)
/MCU/~RNF_PULSE: C73.1, J8.8, R38.2
/MCU/~VBAT_LOW: R14.2, U4.8 (STAT1/~LDB)
/MCU/~WSP_PULSE: C71.1, J8.6, R37.2
/NB MODULE/GPS_LNA_ENA: MD1.H18 (GNSS_LNA_EN), U10.3 (EN)
/NB MODULE/RXD0: MD1.AA15 (RXD0), U9.3 (A)
/NB MODULE/SIM_CLK: C40.1, D6.3 (CH2), J5.C3 (CLK), MD1.L1 (SIM_CLK)
/NB MODULE/SIM_DAT: C38.1, D6.1 (CH1), J5.C7 (I/O), MD1.N1 (SIM_DAT)
/NB MODULE/SIM_RST: C43.1, D6.4 (CH3), J5.C2 (RST), MD1.M2 (SIM_RST)
/NB MODULE/SIM_VCC: C44.2, D6.5 (CH4), J5.C1 (VCC), MD1.P2 (SIM_VCC)
/NB MODULE/TXD0: MD1.Y16 (TXD0), R31.1
/SENSORS/SCL1: J6.7, U12.2 (SCL), U14.4 (SCK/SCL)
/SENSORS/SDA1: J6.8, U12.1 (SDA), U14.3 (SDI/SDA)
/SENSORS/VOUT: C69.1, J6.5, R36.1
/SENSORS/~LED_EN: J6.6, U11.3 (~LED_EN)
GND: ANT1.1 (GND), ANT1.3 (GND), ANT2.2 (GND), ANT2.3 (GND), BAT1.-, BAT2.-, BT1.2, BT2.2, C1.2, C2.2, C3.2, C4.2, C5.-, C6.2, C7.2, C9.2, C12.2, C13.2, C14.2, C15.2, C16.2, C17.2, C18.2, C19.-, C20.-, C21.2, C22.2, C23.2, C24.2, C25.2, C26.-, C27.2, C28.2, C29.2, C30.2, C31.1, C32.2, C33.2, C34.2, C35.2, C36.2, C37.2, C38.2, C39.2, C40.2, C41.2, C42.2, C43.2, C44.1, C45.2, C46.2, C47.2, C48.2, C49.-, C50.1, C51.2, C52.2, C54.2, C55.1, C56.2, C58.-, C59.2, C60.1, C61.2, C62.1, C64.2, C70.2, C71.2, C72.-, C73.2, D5.K, D6.2 (GND), J1.1, J2.2, J3.3, J3.4, J4.6 (GND), J5.C5 (GND), J5.S1 (SHIELD), J5.S2 (SHIELD), J7.3, J7.4, J8.4, J8.5, J8.7, MD1.A3 (GND), MD1.A7 (GND), MD1.A9 (GND), MD1.A13 (GND), MD1.A17 (GND), MD1.B4 (GND), MD1.B6 (GND), MD1.B10 (GND), MD1.B12 (GND), MD1.B14 (GND), MD1.B16 (GND), MD1.C19 (GND), MD1.D18 (GND), MD1.F8 (GND), MD1.F12 (GND), MD1.F18 (GND), MD1.G19 (GND), MD1.H6 (GND), MD1.H14 (GND), MD1.J19 (GND), MD1.K18 (GND), MD1.M18 (GND), MD1.N19 (GND), MD1.P6 (GND), MD1.P14 (GND), MD1.T8 (GND), MD1.T12 (GND), MD1.U1 (GND), MD1.V2 (GND), MD1.W19 (GND), MD1.Y2 (GND), MD1.Y4 (GND), MD2.1 (GND), MD2.2 (GND), MD2.3 (GND), MD2.4 (GND), Q1.2 (S), Q2.2 (S), R3.2, R4.2, R9.2, R12.2, R16.2, R17.2, R18.2, R20.2, R21.1, R30.2, R35.2, TP6.1, U1.1 (GND), U2.2 (PG), U2.4 (GND), U2.6 (FB2), U2.10 (PGND), U2.15 (VSEL), U3.2 (GND), U3.3 (~CE), U3.5 (ST), U4.3 (SEL), U4.9 (~TE), U4.10 (VSS), U4.11 (VSS), U4.21 (EP), U5.1 (GND), U6.4 (GND), U7.6 (VSS), U7.31 (VSS), U7.42 (VSS), U8.2 (GND), U9.2 (GND), U10.2 (GND), U13.2 (GND), X1.2 (GND1), X1.3 (GND2)
GND1: C63.2, C65.-, C66.2, C67.2, C69.2, C74.2, C75.2, J6.3, J6.4, U11.2 (LED_GND), U11.4 (GND), U11.7 (EP), U11.8 (EP), U12.4 (GND), U14.1 (GND), U14.7 (GND)
unnamed: ANT1.2 (SIG), Z1.2
unnamed: ANT2.1 (SIG), C53.2, C56.1, L3.1
unnamed: C11.2, R7.1, R11.2, R12.1, R13.2
unnamed: C21.1, J3.1, R19.1, U4.14 (VBAT), U4.15 (VBAT), U4.16 (VBAT)
unnamed: C57.-, C58.+
unnamed: C68.1, C70.1, C72.+, D8.K, J7.2, R34.1, TP10.1
unnamed: D1.A, U2.7 (VOUT), U2.8 (VOUT)
unnamed: D2.A, L2.2
unnamed: D3.K, R14.1
unnamed: D4.K, R15.2
unnamed: D5.A, R26.2
unnamed: D7.A, R32.2
unnamed: F1.1, J1.4
unnamed: MD1.A5 (CELL_ANT), Z1.1
unnamed: C48.1, C49.+, MD1.N4 (CTANK)
unnamed: C53.1, MD1.E19 (GNSS_ANT)
unnamed: MD1.R1 (PWRMON), Q2.3 (D)
unnamed: MD1.B2 (SLED), Q1.1 (G)
unnamed: C45.1, MD1.T18 (USB_VBUS), R29.2, R30.1
unnamed: C50.2, C52.1, FT1.1, MD1.AA3 (VBATT), MD1.W1 (VBATT_PA)
unnamed: D7.K, Q1.3 (D)
unnamed: R4.1, R5.1, R6.2
unnamed: C8.2, U1.6 (BS)
unnamed: R1.2, R2.1, R3.1, U1.5 (EN)
unnamed: R7.2, U1.4 (FB)
unnamed: C1.1, C5.+, J2.1, R2.2, U1.3 (IN)
unnamed: C8.1, L2.1, U1.2 (SW)
unnamed: C10.2, R8.2, R9.1, R10.2, U2.5 (FB)
unnamed: L1.2, U2.11 (L1)
unnamed: L1.1, U2.9 (L2)
unnamed: C3.1, U2.3 (VAUX)
unnamed: C6.1, C7.1, F1.2, R5.2, TP1.1, U3.1 (VIN)
unnamed: R16.1, U4.13 (PROG1)
unnamed: R17.1, U4.12 (PROG3)
unnamed: R15.1, U4.7 (STAT2)
unnamed: R18.1, U4.5 (THERM)
unnamed: R21.2, U7.17 (AVSS/VSS)
unnamed: C30.1, U7.7 (VCAP)
unnamed: R31.2, U8.4 (B)
unnamed: R28.1, U9.4 (B)
unnamed: C61.1, U10.4 (NC/BP)
unnamed: C65.+, R33.2, U11.1 (VLED)
unnamed: R36.2, U11.5 (VOUT)
unnamed: C68.2, R34.2, R35.1, U13.3 (FB)
unnamed: D8.A, L4.2, U13.1 (SW)
VBAT: BAT1.+, BAT2.+, J3.2, TP5.1
VDD: C2.1, C22.1, C25.1, C26.+, C64.1, L4.1, TP7.1, U2.12 (VIN), U2.13 (VIN), U4.1 (VBAT), U4.20 (VBAT), U5.3 (VIN), U13.5 (IN)
VDD1: C63.1, J6.2, R33.1, U11.6 (VCC)
VIO: C39.1, C41.1, C42.1, R27.2, U8.1 (VCCA), U8.5 (DIR), U9.6 (VCCB)
VLNA: C59.1, C60.2, L3.2, TP9.1, U10.5 (VOUT)
VNB: C10.1, C16.1, C18.1, C19.+, C54.1, C55.2, C57.+, C62.2, D1.K, FT1.2, R8.1, TP2.1, U10.1 (VIN)
VSEN1: C66.1, C67.1, C74.1, C75.1, J6.1, U12.3 (VDD), U14.6 (VDDIO), U14.8 (VDD)

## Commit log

2024-03-17 Điện áp nguồn
    dữ liệu từ datasheet cảm biến
2024-03-17 COMMITDATA.md
    bảng dữ liệu chuẩn
2024-03-17 CHECK1
    thêm nguồn tài liệu
2024-03-22 POWER1
    POWER1
2024-03-22 CHECKV1.0
    CHECK1.0
    [Power.kicad_pcb, Power.kicad_sch, untitled.kicad_sch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]
2024-03-22 Flowchart update
    update
2024-03-26 CHECK
    CHECK1
    [Power.kicad_sch, untitled.kicad_sch, untitled1.kicad_sch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]
2024-03-27 CHECK
    CHECK
    [untitled.kicad_sch, untitled1.kicad_sch, untitled3.kicad_sch]
2024-04-03 FIX
    fix
    [Anemo-Endscrew_Top_FIXED.stl, Anemo_-_EndScrew_Bottom_FIXED.stl, Anemo_Backpole.stl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]
2024-04-05 Case
    case
2024-04-09 UPDATE HARDWARE
    UPDATE
    [Anemo-Endscrew_Top_FIXED.stl, Anemo_-_EndScrew_Bottom_FIXED.stl, Anemo_Backpole.stl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]
2024-04-11 UPDATE outline
    update outline
    [WeatherStation.kicad_pcb]
2024-04-11 update outline
    outline
    [WeatherStation.kicad_pcb]
2024-04-12 UPDATE _FOOTPRINT
    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
    [022035025.stp, 022286020.stp, 0402C.step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]
2024-04-15 Update check BoM
    update BoM
    [MCU.kicad_sch, NBMODULE.kicad_sch, POWER.kicad_sch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]
